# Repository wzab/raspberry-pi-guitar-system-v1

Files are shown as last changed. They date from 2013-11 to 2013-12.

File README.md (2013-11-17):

raspberry-pi-guitar-system-v1
=============================

Open Hardware/Open Software extension board for Raspberry Pi to connect an electric guitar to a virtual amplifier via network (e.g. WiFi)

The idea of this system was presented in the thread: https://groups.google.com/forum/#!topic/comp.sys.raspberry-pi/EgQAQ0DNwN4

The repository will contain both Kicad project of the hardware, and sources of the software.

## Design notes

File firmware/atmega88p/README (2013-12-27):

This directory will store firmware for ATmega88p microcontroller used in the
extension board.

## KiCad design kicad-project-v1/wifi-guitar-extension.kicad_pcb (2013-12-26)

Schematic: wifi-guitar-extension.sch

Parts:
C1, C2, C3, C5, C6: 1u
C4, C7: 22p
IC1: ATMEGA88PA-A; TQFP32
K1: CONN_3
P1: CONN_13X2
P2: CONN_4X2
P3: CONN_2
P4: CONN_10X2
R1: 200k
R2, R7, R8: 3k
R3: 150
R4, R5, R6: 10k
U1: CS5343; TSSOP-10
X1: 12.288MHz

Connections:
/CS5343_MCLK: IC1.12 ((PCINT0/CLKO/ICP1)PB0), U1.4 (MCLK)
/POT_1: IC1.22 (ADC7), P4.3
/POT_2: IC1.26 ((PCINT11/ADC3)PC3), P4.4
/POT_3: IC1.25 ((PCINT10/ADC2)PC2), P4.5
/POT_4: IC1.23 ((PCINT8/ADC0)PC0), P4.6
/POT_5: IC1.19 (ADC6), P4.7
/POT_6: IC1.24 ((PCINT9/ADC1)PC1), P4.8
/RPI_PCM_CLK: P2.3, R6.2, U1.2 (SCLK)
/RPI_PCM_DIN: P2.5, R4.2, U1.1 (SDOUT)
/RPI_PCM_FS: P2.4, R5.2, U1.3 (LRCK)
/RPI_RXD: K1.3, P1.10
/RPI_SCL: IC1.28 ((PCINT14/SCL/ADC5)PC5), P1.5, R8.1
/RPI_SDA: IC1.27 ((PCINT12/SDA/ADC4)PC4), P1.3, R7.1
/RPI_TXD: K1.2, P1.8
/RPI_uC_MISO: IC1.16 ((PCINT4/MISO)PB4), P1.21
/RPI_uC_MOSI: IC1.15 ((PCINT3/OC2A/MOSI)PB3), P1.19
/RPI_uC_RESET: IC1.29 ((PCINT14/~RESET~)PC6), P1.22
/RPI_uC_SCK: IC1.17 ((PCINT5/SCK)PB5), P1.23
/SW1: IC1.1 ((PCINT19/OC2B/INT1)PD3), P4.11
/SW2: IC1.32 ((PCINT18/INT0)PD2), P4.12
/SW3: IC1.9 ((PCINT21/OC0B/T1)PD5), P4.13
/SW4: IC1.2 ((PCINT20/XCK/T0)PD4), P4.14
/SW5: IC1.11 ((PCINT23/AIN1)PD7), P4.15
/SW6: IC1.10 ((PCINT22/OC0A/AIN0)PD6), P4.16
/SW7: IC1.14 ((PCINT2/OC1B/~SS~)PB2), P4.17
/SW8: IC1.13 ((PCINT1/OC1A)PB1), P4.18
/V3,3: C5.1, C6.1, IC1.4 (VCC), IC1.6 (VCC), P1.1, P1.17, P4.1, P4.2, R3.1, R4.1, R5.1, R6.1, R7.2, R8.2, U1.10 (VA)
GND: C3.2, C4.2, C5.2, C6.2, C7.2, IC1.3 (GND), IC1.5 (GND), IC1.21 (GND), K1.1, P1.6, P1.9, P1.14, P1.20, P1.25 (P24), P3.2 (PM), P4.9, P4.10, P4.19, P4.20, R1.2, U1.9 (GND)
unnamed: C7.1, IC1.7 ((PCINT6/XTAL1/TOSC1)PB6), X1.2
unnamed: C1.1, U1.6 (AINL)
unnamed: C2.1, U1.8 (AINR)
unnamed: P3.1, R2.2
unnamed: C1.2, C2.2, R1.1, R2.1
unnamed: C3.1, IC1.18 (AVCC), IC1.20 (AREF), R3.2
unnamed: C4.1, IC1.8 ((PCINT7/XTAL2/TOSC2)PB7), X1.1

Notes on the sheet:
Analog input and ADC
Resistors configuring the ADC speed. For 48kHz sampling with 12.288MHz crystal, we should select SSM with 256x multiplication factor, so neither R5 nor R6 should be mounted. R4 should be mounted, as it enforces the Master Mode
Please note, that P2 is mounted on the same side of PCB as P1, but pin numbers are located as it was mounted on the oposite side!

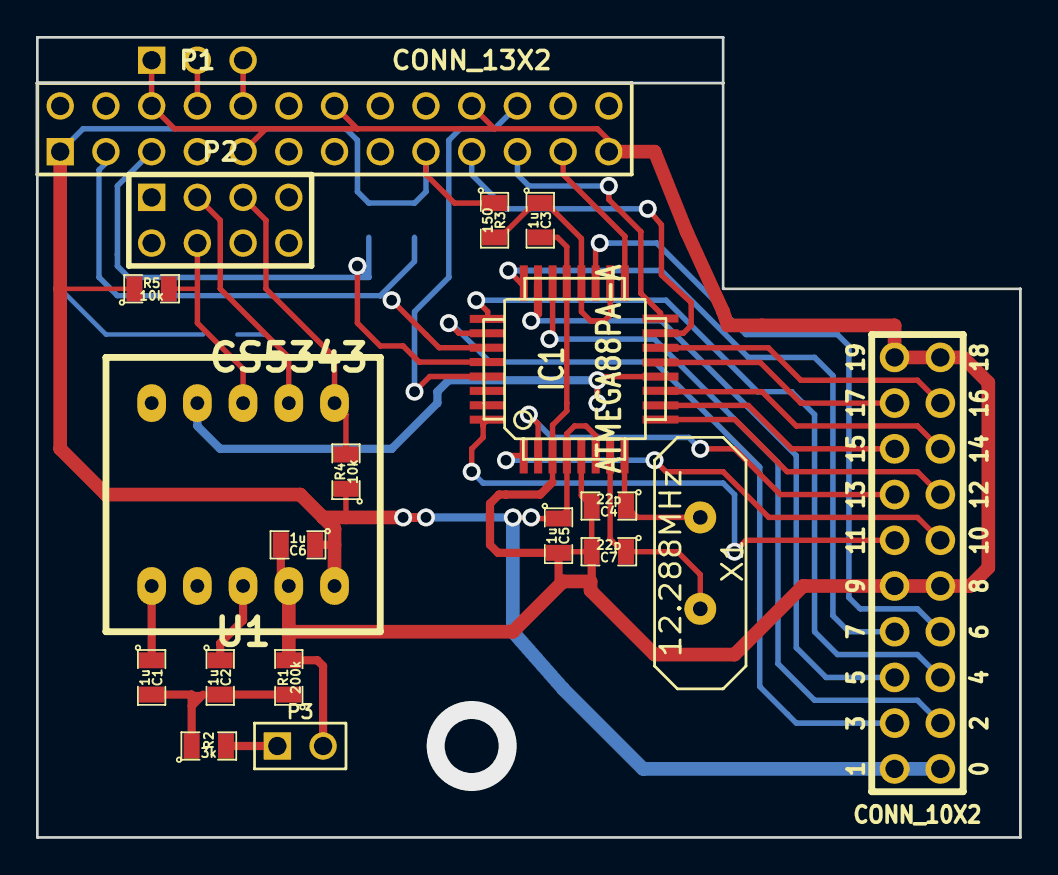
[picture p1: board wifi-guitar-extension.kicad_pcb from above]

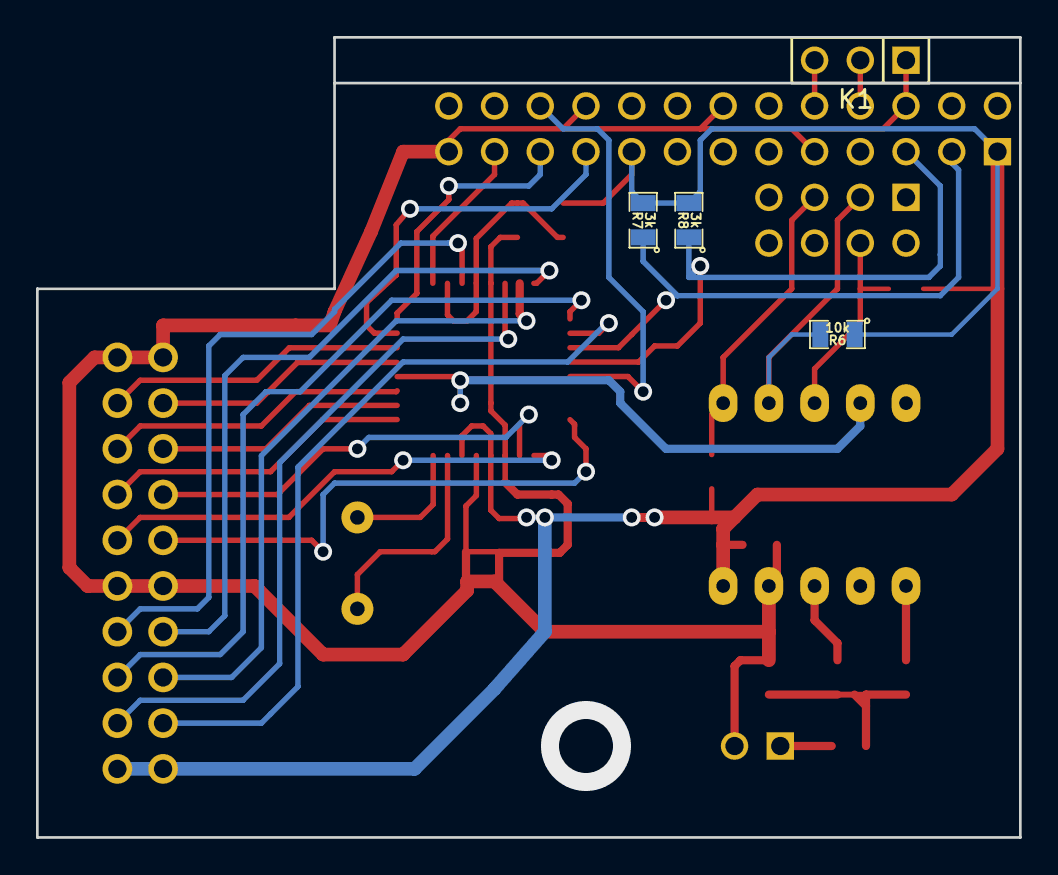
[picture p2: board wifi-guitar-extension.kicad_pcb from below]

Board: 2 copper layers, 54.6 x 44.4 mm, 23 parts (4 on the bottom side), 35 nets.

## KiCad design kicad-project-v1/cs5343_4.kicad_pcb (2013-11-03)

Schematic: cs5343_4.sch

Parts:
C1, C5, C7: 100n
C2, C6, C8: 1u
C3, C4: 180p
P1, P2: CONN_5
U1: CS5343; TSSOP-10

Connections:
GND: C1.2, C2.2, C3.2, C4.2, C5.2, C6.2, C7.2, C8.2, P2.2, U1.9 (GND)
unnamed: C3.1, P2.3, U1.8 (AINR)
unnamed: P1.4, U1.4 (MCLK)
unnamed: P1.3, U1.3 (LRCK)
unnamed: P1.2, U1.2 (SCLK)
unnamed: P1.1, U1.1 (SDOUT)
unnamed: C7.1, C8.1, P2.1, U1.10 (VA)
unnamed: C5.1, C6.1, P2.4, U1.7 (VQ)
unnamed: C1.1, C2.1, P1.5, U1.5 (FILT+)
unnamed: C4.1, P2.5, U1.6 (AINL)

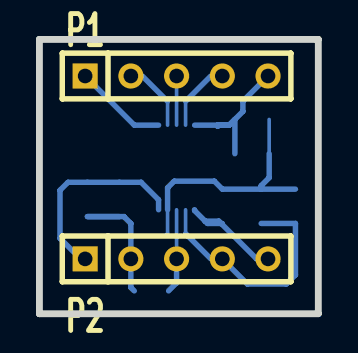
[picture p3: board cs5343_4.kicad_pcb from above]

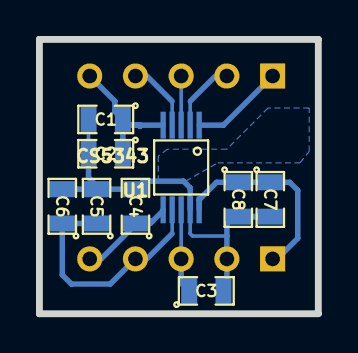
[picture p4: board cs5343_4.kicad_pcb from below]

Board: 2 copper layers, 15.5 x 15.2 mm, 11 parts (9 on the bottom side), 10 nets.

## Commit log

2013-11-03 Commited first version of schematic and PCB design. Please note, that this version uses ATmega88 uC, running at 3.3V Vcc and 12.288 MHz clock. The ATmega88 uC is used as: 1. Clock source for CS5343/4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
    State of switches and potentiometers is reported do RPi via
    I2C interface (ATmega is I2C slave).
    ATmega may be programmed from the RPi using the avrdude program,
    as described in
    http://kevincuzner.com/2013/05/27/raspberry-pi-as-an-avr-programmer/
    [cs5343_4.kicad_pcb, cs5343_4.sch, wifi-guitar-extension.kicad_pcb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]
2013-12-26 Added resistor pulling up the SDOUT line in CS534x (to ensure the Master Mode). Added optional connector for connecting the UART.
    [cs5343_4.sch, wifi-guitar-extension.kicad_pcb, wifi-guitar-extension.sch]
